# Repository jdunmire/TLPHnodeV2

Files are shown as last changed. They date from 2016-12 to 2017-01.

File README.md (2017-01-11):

TLPHnodeV2
==========
This is a [KiCad](http://kicad-pcb.org/) project for an ESP8266 based
temperature, light, pressure, and humidity node.

Additional information about this node can be found at the 
[Sensor Nodes](http://sensornodeinfo.rockingdlabs.com) website.

Copyright Jerry Dunmire 2017.

This documentation describes Open Hardware and is licensed under the
CERN OHL v. 1.2.

You may redistribute and modify this documentation under the terms of
the CERN OHL v.1.2. (LICENSE.txt). This documentation is distributed
WITHOUT ANY EXPRESS OR IMPLIED WARRANTY, INCLUDING OF MERCHANTABILITY,
SATISFACTORY QUALITY AND FITNESS FOR A PARTICULAR PURPOSE. Please see
the CERN OHL v.1.2 for applicable conditions

Guidelines on how to apply the CERN OHL v1.2 are in the
cern_ohl_v_1_2_howto.pdf file.

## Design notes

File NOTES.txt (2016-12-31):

###Fri 25 Nov 2016 04:06:11 PM PST
    - For a rechargable option:
       - LiFePO4 18350 sized battery
       - bq25070 ($2.46) or ADP5063 ($3.43) charger
       - MIC5528 ($0.19) or AP7365 ($0.40) 3.3v linear regulator
       - Use battery holder with lugs or wires
       - The chargers can yield a battery output voltage 4.9v, or
         possibly higher. So a regulator is needed.
       - Watch for quiesent currents (which are similar to the ESP8266!)

    - The TLPHnode board should be minimized to reduce cost. Use wires
      to the power source which could be 2 Alkaline AA, or a single
      LiFePO4.

    - The charging circuit could be on the PCB but not populated.

    - The linear regulator could be used to provide a USB powered
      option with the AA batteries as backup.

###Sun 27 Nov 2016 11:38:00 AM PST
    - Use a 6 pin connector and ribbon so that the prgm switch can be
      moved to the 'programming' board.
    - Use a LDO linear regulator on the sensor board to protect from
      over voltage of LiFePO4, or even LiPoly, batteries.
    - Put the battery charger IC on the programming board or a separate
      battery supply board.
    - The 'programming' board can be fab as part of the sensor board.
      Use holes or a cutout to make it easier to separate the board.

###Mon 05 Dec 2016 11:53:34 AM PST
    - ST Micro is not forthcoming on the adjustable regulator. So try
      the fixed, even though it is small. Consider laying out a foot
      print for an alternative regulator in addition to the ST Micro.
      I'm not ready to give up on the ST Micro regulator because it has
      such a log quesent current.
      
    TODO:
      - fix alignment between ESP-12 model and ESP-12E footprint - DONE
      - Change pin numbering on ESP-12E footprint to match ESP-12 - DONE
      - change to ESP-12
      - Re-organize footprints - DONE
      - Add 3d models
            - Regulator - flipchip-4
            - RPC connector
            - Switch
            
      - Settle on FPC connector (datasheet is wrong)
      - Update BOM at Digikey
      - 

###Tue 06 Dec 2016 10:00:03 AM PST
    - In order to use a 4 layer board for less than the cost of the last
      board, the area must be less than 1.42 square inches.
    - Keep in mind that a 2 layer board is still 1/2 of that price, but
      the there are other advantages including smaller traces, drills
      and annual rings.

    LIBRARIES
    ---------
    KiCAD has three collections that could be described as libraries:
        - schematic symbols (typically in a library/ directory)
        - 3d models (typically in a modules/packages3d/ directory)
        - footprints
          These are the tough ones to keep straight.
            - The new 'footprint collection structure' is a directory of
              directories.
            - Each sub-directory ends in .pretty.
            - Actual footprints are in individual files beneath the
              *.pretty/ directories.
            - Each *.pretty directory must be added as a separate path.
            - Each *.pretty directory is an individual git repository.
            - There is not clear parent directory name, though in
              ~/kicad/README.md I proposed putting them in the modules/
              directory with the 3d-models

###Thu 08 Dec 2016 09:47:13 PM PST
    - The LPS25HB (pressure sensor) can not be used on an OSH 2 layer
      board because there is not enough clearance between the corner
      pins. The error is 0.3 mils.
    - Set the default design rules as close to the 2 layer as possible,
      while allowing the LPS25HB to be used.

###Mon 12 Dec 2016 02:35:20 PM PST
    - Changed to 6-pin FPC connnector and 2-pin through-hole connector
      for power.

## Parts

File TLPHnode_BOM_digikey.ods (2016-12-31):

 | Source | /home/jerry/Dropbox/TLPHnode/TLPHnode.sch
 | Kicad Rev | Eeschema no-vcs-found-7400~56~ubuntu16.04.1
 | Generated Date | Fri 16 Dec 2016 08:55:06 AM PST
 | Title | TLPH Node
 | Company | RockingDLabs
 | Revision | Not Set
 | Date Issue | Not Set
 | Comment | http://sensornodeinfo.rockingdlabs.com
Digikey PN | Reference | Value | Library | Library Ref
336-3124-5-ND | U4 | Si7006-A20 | rockingdlabs | Si7006-A20 | x
490-1532-1-ND | C2 | 0.1 uF | device | C | x
490-1532-1-ND | C4 | 0.1 uF | device | C
490-1532-1-ND | C5 | 0.1 uF | device | C
490-1532-1-ND | C6 | 0.1 uF | device | C
490-1536-1-ND | C1 | 1 uF | device | C | x
490-1536-1-ND | C3 | 1 uF | device | C
497-14210-1-ND | U2 | LD39130S | rockingdlabs | LD39130S | x
497-15070-1-ND | U3 | LPS25HB | rockingdlabs | LPS25HB | x
EG4621CT-ND | SW1 | Reset | TLPHnode-cache | SW_Push | x
ISL29035IROZ-T7CT-ND | U6 | ISL29035 | rockingdlabs | ISL29035 | x
NCP703SN33T1GOSCT-ND | U1 | NCP703 | rockingdlabs | NCP703 | x
RHM10.0KHCT-ND | R5 | 10k | device | R | x
RHM10.0KHCT-ND | R6 | 10k | device | R
RHM10.0KHCT-ND | R7 | 10k | device | R
RHM4.70KCFCT-ND | R1 | 4.7k | device | R | x
RHM4.70KCFCT-ND | R10 | 4.7k | device | R
RHM4.70KCFCT-ND | R11 | 4.7k | device | R
RHM4.70KCFCT-ND | R12 | 4.7k | device | R
RHM4.70KCFCT-ND | R13 | 4.7k | device | R
RHM4.70KCFCT-ND | R14 | 4.7k | device | R
RHM4.70KCFCT-ND | R2 | 4.7k | device | R
RHM4.70KCFCT-ND | R3 | 4.7k | device | R
RHM4.70KCFCT-ND | R4 | 4.7k | device | R
RHM4.70KCFCT-ND | R8 | 4.7k | device | R
RHM4.70KCFCT-ND | R9 | 4.7k | device | R
 | P1 | Bat | conn | CONN_01X02
609-4331-1-ND | P2 | CONN_01X06 | conn | CONN_01X06 | x
 | U5 | ESP-12E | ESP8266 | ESP-12E
 |  |  |  |  | 11
$11.09

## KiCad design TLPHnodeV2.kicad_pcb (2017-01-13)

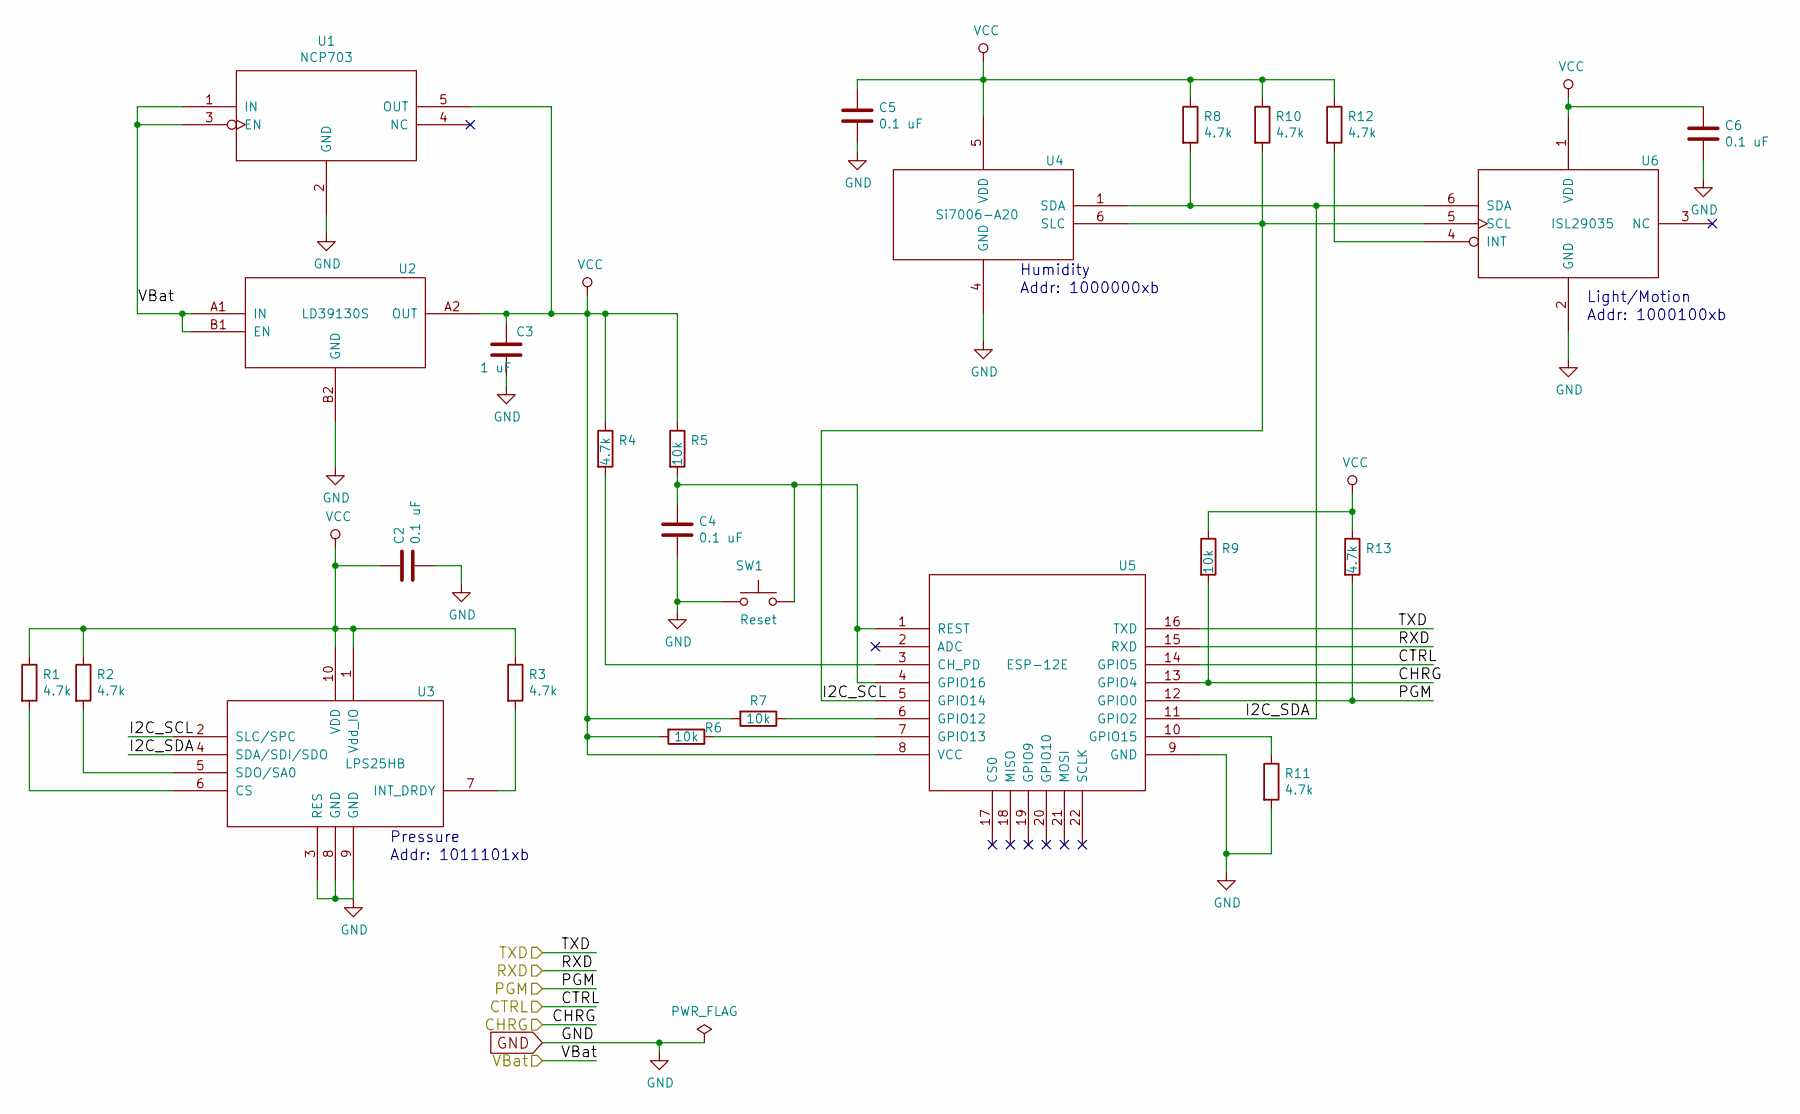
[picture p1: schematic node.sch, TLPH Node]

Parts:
C2, C4, C5, C6: 0.1 uF; C_0603
C3: 1 uF; C_0603
R1, R2, R3, R4, R8, R10, R11, R12, R13: 4.7k; R_0603
R5, R6, R7, R9: 10k; R_0603
SW1: Reset; ESwitch-SMD-4
U1: NCP703; NCP703-TSOP-5
U2: LD39130S; LD39130S-FlipChip-4
U3: LPS25HB; LPS25HB-HLGA-10L-2.5x2.5mm
U4: Si7006-A20; Si7006_A20-DFN-6
U5: ESP-12E
U6: ISL29035; ISL29035-DFN-6-1.5x1.6mm_Pitch0.5mm

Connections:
+BATT: U1.1 (IN), U1.3 (EN), U2.A1 (IN), U2.B1 (EN); also elsewhere on the board
/node/CHRG: R9.2, U5.13 (GPIO4); also elsewhere on the board
/node/CTRL: U5.14 (GPIO5); also elsewhere on the board
/node/I2C_SCL: R10.2, U3.2 (SLC/SPC), U4.6 (SLC), U5.5 (GPIO14), U6.5 (SCL)
/node/I2C_SDA: R8.2, U3.4 (SDA/SDI/SDO), U4.1 (SDA), U5.11 (GPIO2), U6.6 (SDA)
/node/PGM: R13.2, U5.12 (GPIO0); also elsewhere on the board
/node/RXD: U5.15 (RXD); also elsewhere on the board
/node/TXD: U5.16 (TXD); also elsewhere on the board
GND: C2.2, C3.2, C4.2, C5.2, C6.2, R11.2, SW1.1, U1.2 (GND), U2.B2 (GND), U3.3 (RES), U3.8 (GND), U3.9 (GND), U4.4 (GND), U5.9 (GND), U6.2 (GND); also elsewhere on the board
unnamed: C4.1, R5.2, SW1.2, U5.1 (REST), U5.4 (GPIO16)
unnamed: R1.2, U3.6 (CS)
unnamed: R2.2, U3.5 (SDO/SA0)
unnamed: R3.2, U3.7 (INT_DRDY)
unnamed: R4.2, U5.3 (CH_PD)
unnamed: R6.1, U5.7 (GPIO13)
unnamed: R7.1, U5.6 (GPIO12)
unnamed: R11.1, U5.10 (GPIO15)
unnamed: R12.2, U6.4 (INT)
VCC: C2.1, C3.1, C5.1, C6.1, R1.1, R2.1, R3.1, R4.1, R5.1, R6.2, R7.2, R8.1, R9.1, R10.1, R12.1, R13.1, U1.5 (OUT), U2.A2 (OUT), U3.1 (Vdd_IO), U3.10 (VDD), U4.5 (VDD), U5.8 (VCC), U6.1 (VDD)

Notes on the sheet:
Pressure
Light/Motion
Humidity
Addr: 1011101xb
Addr: 1000000xb
Addr: 1000100xb

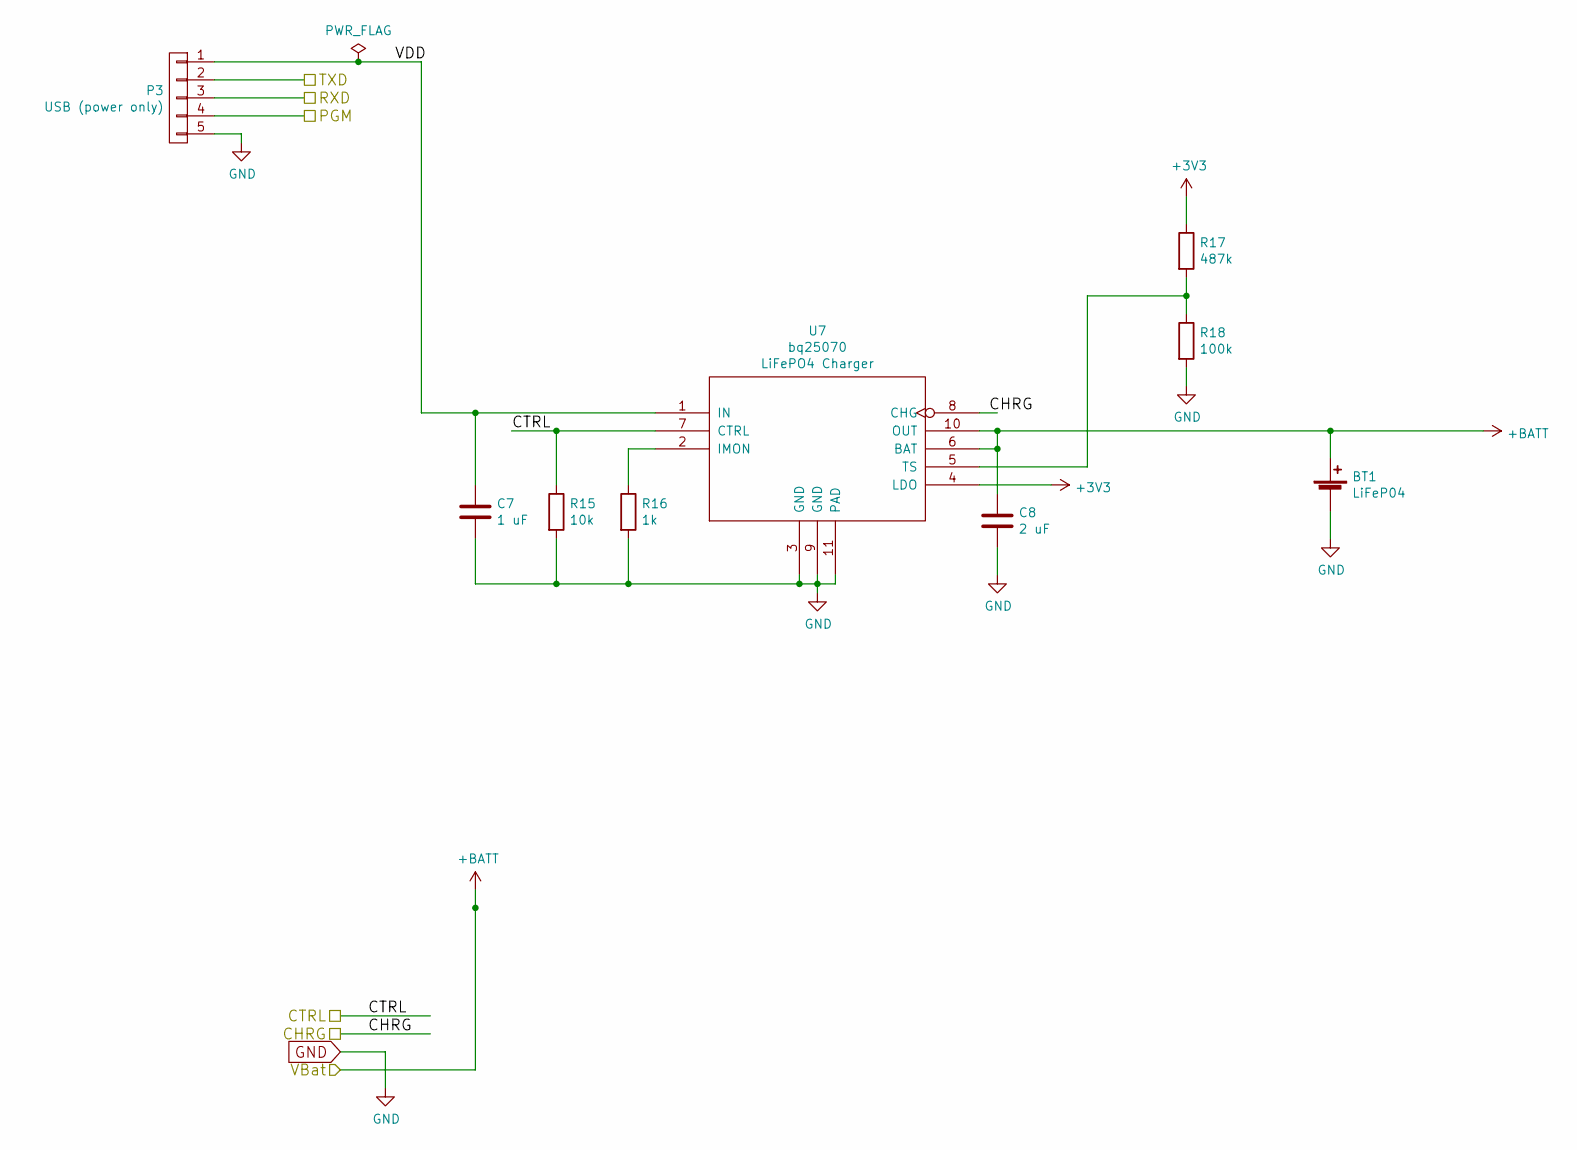
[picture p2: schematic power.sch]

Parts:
BT1: LiFeP04; JST_PH_B2B-PH-SM4-TB_02x2.00mm_Straight
C7: 1 uF; C_0603
C8: 2 uF; C_0603
P3: USB (power only); USB_Micro-B_10103594-0001LF
R15: 10k; R_0603
R16: 1k; R_0603
R17: 487k; R_0603
R18: 100k; R_0603
U7: bq25070; bq25070_DQC_10-DQC10_P84X2P4

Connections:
+3V3: R17.1, U7.4 (LDO)
+BATT: BT1.1 (+), C8.1, U7.6 (BAT), U7.10 (OUT); also elsewhere on the board
/node/CHRG: U7.8 (CHG); also elsewhere on the board
/node/CTRL: R15.1, U7.7 (CTRL); also elsewhere on the board
/node/PGM: P3.4; also elsewhere on the board
/node/RXD: P3.3; also elsewhere on the board
/node/TXD: P3.2; also elsewhere on the board
/power/VDD: C7.1, P3.1, U7.1 (IN)
GND: BT1.2 (-), C7.2, C8.2, P3.5, R15.2, R16.2, R18.2, U7.3 (GND), U7.9 (GND), U7.11 (PAD); also elsewhere on the board
unnamed: R16.1, U7.2 (IMON)
unnamed: R17.2, R18.1, U7.5 (TS)

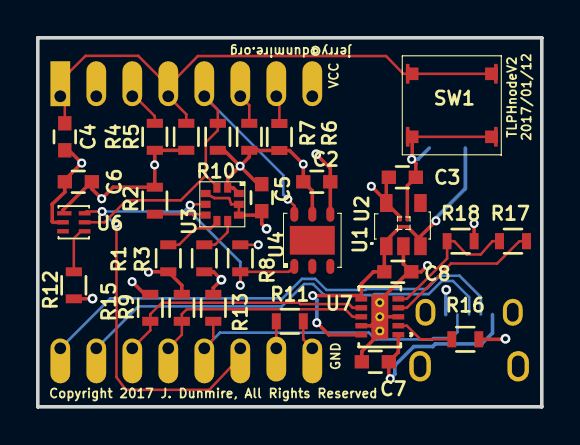
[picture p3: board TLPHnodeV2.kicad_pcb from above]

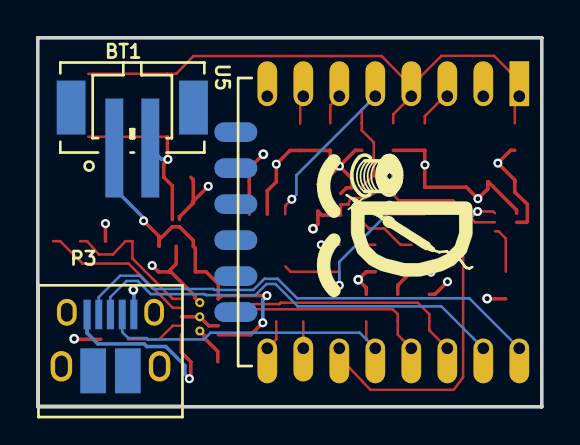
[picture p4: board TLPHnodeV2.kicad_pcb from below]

Board: 4 copper layers, 28.0 x 20.5 mm, 35 parts (4 on the bottom side), 23 nets.

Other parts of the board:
Ref**: RockingDLogo_9x7

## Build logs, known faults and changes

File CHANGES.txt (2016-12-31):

This file is for changes made by Licensee. See section 3.4b of the CERN
Open Hardware License v1.2 (LICENSE.txt).

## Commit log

2016-12-31 Combine TLPHnode and nodePwr
    - Create a single board based on the two original
    - Battery connector (BT1) has been changed from rt-angle to vert.
    On branch master
    [TLPHnodeV2.kicad_pcb, TLPHnodeV2.sch, TLPHnode_BOM_digikey.ods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]
2016-12-31 Get ready for new routing
    - remove old parts and all traces
    - import new netlist
    modified: TLPHnodeV2.kicad_pcb
    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
    [TLPHnodeV2.kicad_pcb]
2016-12-31 Remove extra resistor on CTRL
    modified: TLPHnodeV2.net
    modified: node.sch
    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
    [node.sch]
2016-12-31 Remove C1
    - C8 should be adequate for both the regulators (U1, U2) and the
    charger (U7)
    [node.sch]
2016-12-31 CP- initial placement
    modified: TLPHnodeV2.pro
    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
    [TLPHnodeV2.kicad_pcb]
2016-12-31 CP - refined placement
    - Rotated battery connector
    [TLPHnodeV2.kicad_pcb]
2016-12-31 CP - routing started
    - Need two swap CTRL and CHRG to make routing cleaner
    [TLPHnodeV2.kicad_pcb]
2016-12-31 Swap ESP-8266 signals for charger control
    - Swap CHRG and CTRL to make layout cleaner
    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
    [TLPHnodeV2.kicad_pcb, node.sch]
2016-12-31 CP - signals routed
    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
    [TLPHnodeV2.kicad_pcb]
2017-01-07 Relocate USB connector to side
    [TLPHnodeV2.kicad_pcb]
2017-01-08 CP - before swapping CHRG and CTRL
    [TLPHnodeV2.kicad_pcb]
2017-01-08 CP - Swapped CTRL and CHRG
    On branch usbSide
    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
    [node.sch]
2017-01-08 CP - move R9 to follow CRTL and CHRG
    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
    [node.sch]
2017-01-08 CP - routed and passed DRC
    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
    [TLPHnodeV2.kicad_pcb]
2017-01-13 Move traces and add logo
    - move a few traces so that they won't be exposed through the solder
    mask
    - Add a logo
    - Set the date
    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
    [TLPHnodeV2.kicad_pcb]
2017-01-13 Save version used to generate gerber files
    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
    [TLPHnodeV2.kicad_pcb]
2017-01-13 Change board name to TLPHnodeV2
    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
    [TLPHnodeV2.kicad_pcb]
2017-02-03 Fix NCP703 symbol
    Pin 3 EN was marked as an inverted clock. It is actually a logic signal
    that should be pulled up to enable.

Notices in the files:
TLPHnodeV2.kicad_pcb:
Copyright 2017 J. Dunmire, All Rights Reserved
